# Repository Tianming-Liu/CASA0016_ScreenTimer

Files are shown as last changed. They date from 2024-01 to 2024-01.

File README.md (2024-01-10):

# *ScreenTimer*
## **CASA0016 Course Work** 
### _A Device for Screen Usage Detection and Data Visualization_

In this project, I designed a **physical device** to **detect and record** the usage time of various screens in daily life, such as the mobile phone and laptop. The primary goal is to **visually display** this data on an **interesting flip clock**.

<div align=center>
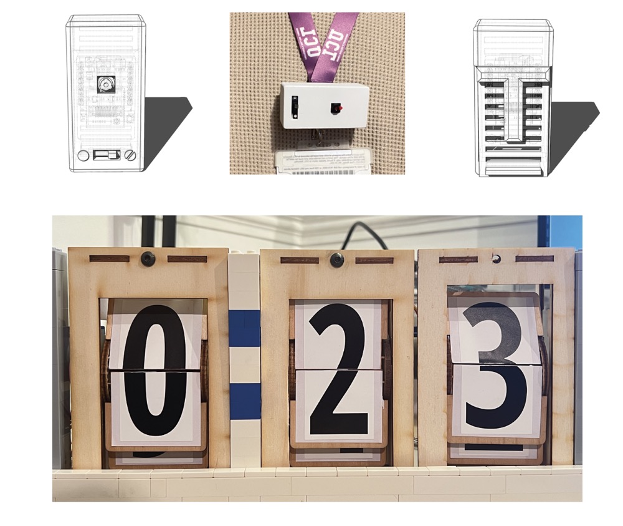
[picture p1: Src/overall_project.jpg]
Overall Photo of Website and Plant Monitor
  
</div>

## Folder Structure

```none
Screen Timer Project
├── Code (All the code for Arduino UNO, ESP32 and Rasberry Pi)
│   ├── Arduino (Code tested on Arduino UNO R4 Wifi)
│   │   ├── Final_Mqtt_MultiMotor (Integrated Code)
│   │   │   ├── Final_Mqtt_MultiMotor.ino (Main Part)
│   │   │   ├── wifiConfig.h (Create your own config file!!)
│   │   ├── Hall_Effect_Sensor_Test
│   │   │   ├── Hall_Effect_Sensor_Test.ino
│   │   ├── IO_Extender_Motor
│   │   │   ├── IO_Extender_Motor.ino
│   │   ├── LDR_Test
│   │   │   ├── LDR_Test.ino
│   │   ├── WiFiS3_test
│   │   │   ├── WiFiS3_test.ino
│   ├── ESP32 (Code tested on ESP32 With CAM Module)
│   │   ├── app_httpd.cpp
│   │   ├── camera_index.h
│   │   ├── camera_pins.h
│   │   ├── CameraWebServer.ino
│   │   ├── wifiConfig.h
│   ├── Rasp_Pi (Code tested on Rasp Pi 4B)
│   │   ├── mqttConfig.py (Create your own config file!!)
│   │   ├── test.py (Main Part)
│   │   ├── yolov8n.pt (Pretrained Model ckpt file)
├── Enclosure
│   ├── video_collection_component_enclosure.3dm (File for 3d printing)
│   ├── Enclosure/laserCut.dxf (File for Laser Cutting)
├── Src (Image and gif for README)
│   ├── ...
├── .gitignore
├── README.md (Intro)

```

## Parts List
The device consists of three components: the Video collection component, the data processing component, and the time display component.
### 1. Video Collection Component
**1.1 FREENOVE ESP32-WROVER CAM Board**

_To minimize the size of our visual data collection device while ensuring essential functionality._

<table>
  <tr>
    <td>
      <p><b>Microprocessor Selection:</b></p>
      <ul>
        <li><i>ESP32 Series</i>: Renowned for its efficiency, the ESP32 series microprocessor has been chosen for its ability to strike an optimal balance between a small form factor and robust performance.</li>
      </ul>
      <p><b>Key Benefits:</b></p>
      <ul>
        <li><i>Seamless Image Capture</i>: Compact camera module ensures high-quality data acquisition.</li>
        <li><i>Effortless Connectivity</i>: Wireless network connection module facilitates easy and reliable data transmission.</li>
      </ul>
    </td>
    <td>
      <div align="center">
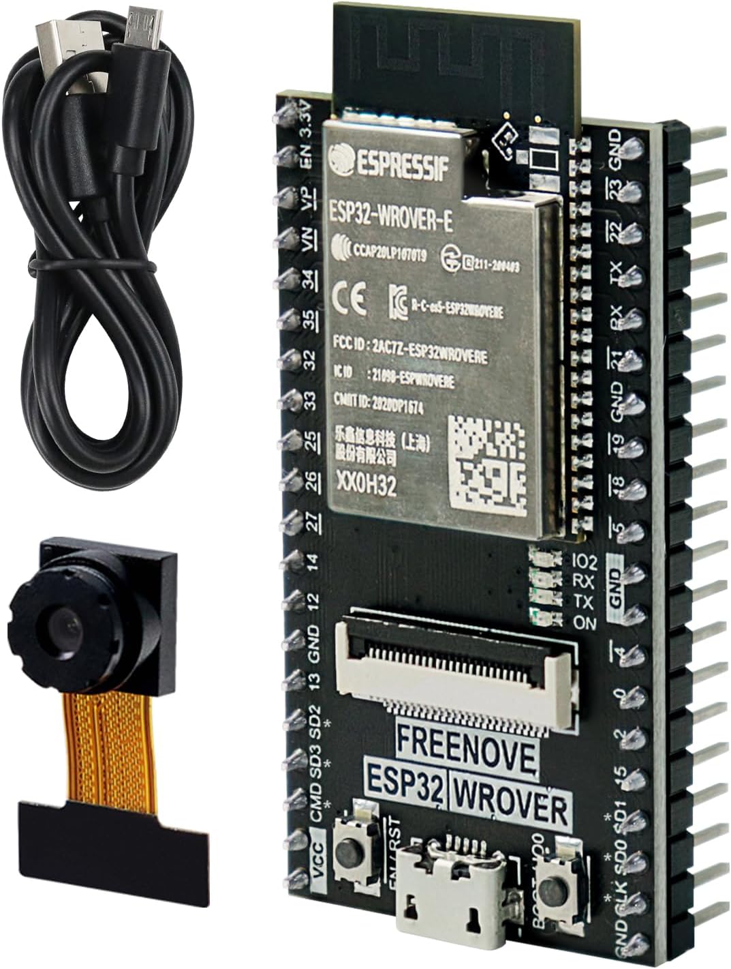
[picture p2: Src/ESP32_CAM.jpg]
        
      </div>
    </td>
  </tr>
</table>

**1.2 Lithium Polymer Battery**

_In choosing components for our project, i want to ensure that my device remains portable while delivering robust performance._

<table>
  <tr>
    <td>
      <p><b>Power Supply Selection:</b></p>
      <ul>
        <li><i>Lithium Polymer batteries</i>: are known for their high energy density and flexible form factor. Unlike traditional rigid batteries, they can be made in various shapes and sizes, which allows for more versatile design options. Their chemistry offers a good balance between weight and energy output, making them popular in portable electronics.</li>
      </ul>
      <p><b>Key Benefits:</b></p>
      <ul>
        <li><i>High Compatibility</i>: With a 3.7V nominal voltage, the Lithium Polymer battery aligns well with the ESP32's 3.3V operation.</li>
        <li><i>Compact and Lightweight</i>: Dimensions of 34.5 x 56 x 10.6 mm and a weight of 40g make this battery an excellent choice for maintaining portability.</li>
        <li><i>Efficient Energy Storage</i>: A capacity of 2000 mAh provides a reliable and long-lasting power source, suitable for extended device operation.</li>
      </ul>
    </td>
    <td>
      <div align="center">
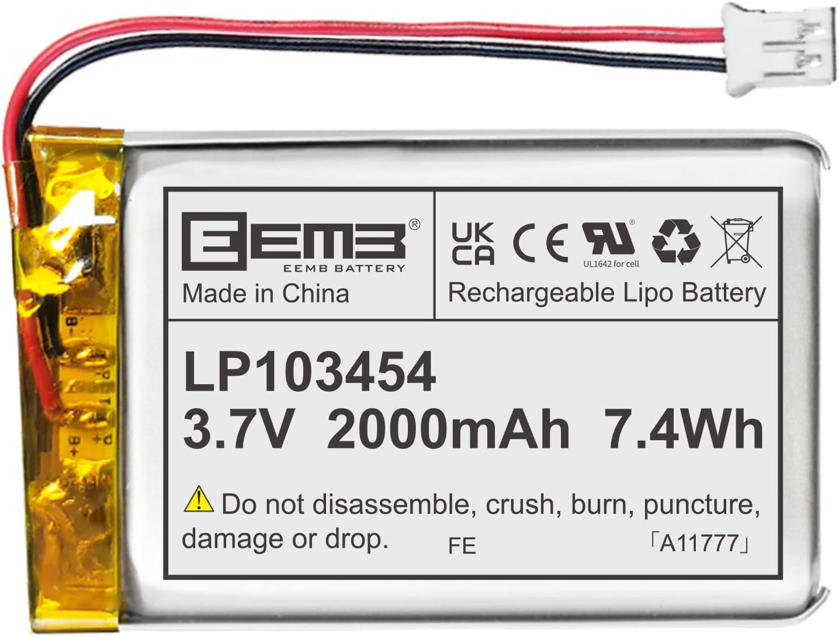
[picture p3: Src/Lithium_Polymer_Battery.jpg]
        
      </div>
    </td>
  </tr>
</table>

**1.3 Slide Switches With 3 Pin 2 Position**

_The module includes a 3-Pin 2-Position switch as the primary control for activating the screen detection device._

<table>
  <tr>
    <td>
      <p><b>Switch Type:</b></p>
      <ul>
        <li><i>Slide Switches With 3 Pin 2 Position</i> are known for its reliability and versatility, offering a clear on/off state without ambiguity. Its 3-pin configuration allows for straightforward integration into the circuit, simplifying the design and assembly process.</li>
      </ul>
      <p><b>Activation Process:</b></p>
      <ul>
        <li>When switched on, the device powers up and initiates the video data collection from the integrated camera.</li>
        <li>The captured video data is then transmitted to the data processing module for analysis.</li>
      </ul>
    </td>
    <td>
      <div align="center">
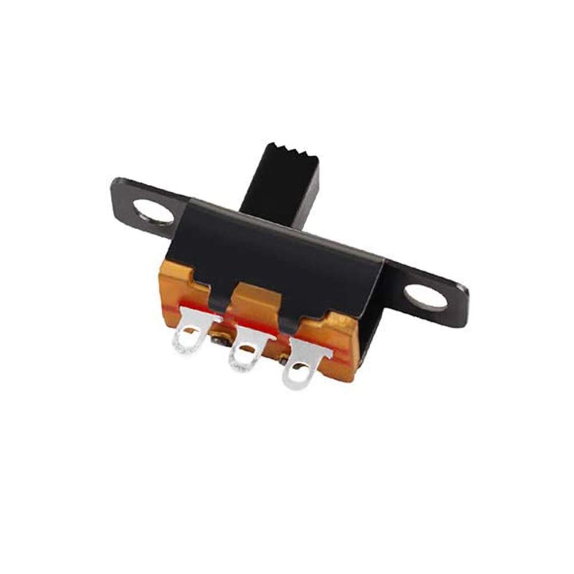
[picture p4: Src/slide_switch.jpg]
        
      </div>
    </td>
  </tr>
</table>

**1.4 3D Enclosure**

_I designed the enclosure for this component and print it out which can be attached to your clothes._

The enclosure I designed is installed in a pin-like manner, allowing for easy placement of the battery and ESP32 inside the box. There are two small holes on the front of the box; the middle opening is for the camera, and the lower opening is for toggling the switch. Symbols are placed on both sides to indicate the current status of the device. The back of the box features a clip-like design, making it convenient to attach the entire data collection box to clothing or a lanyard.

<table align=""center>
  <tr>
    <td>
        <div align="center">
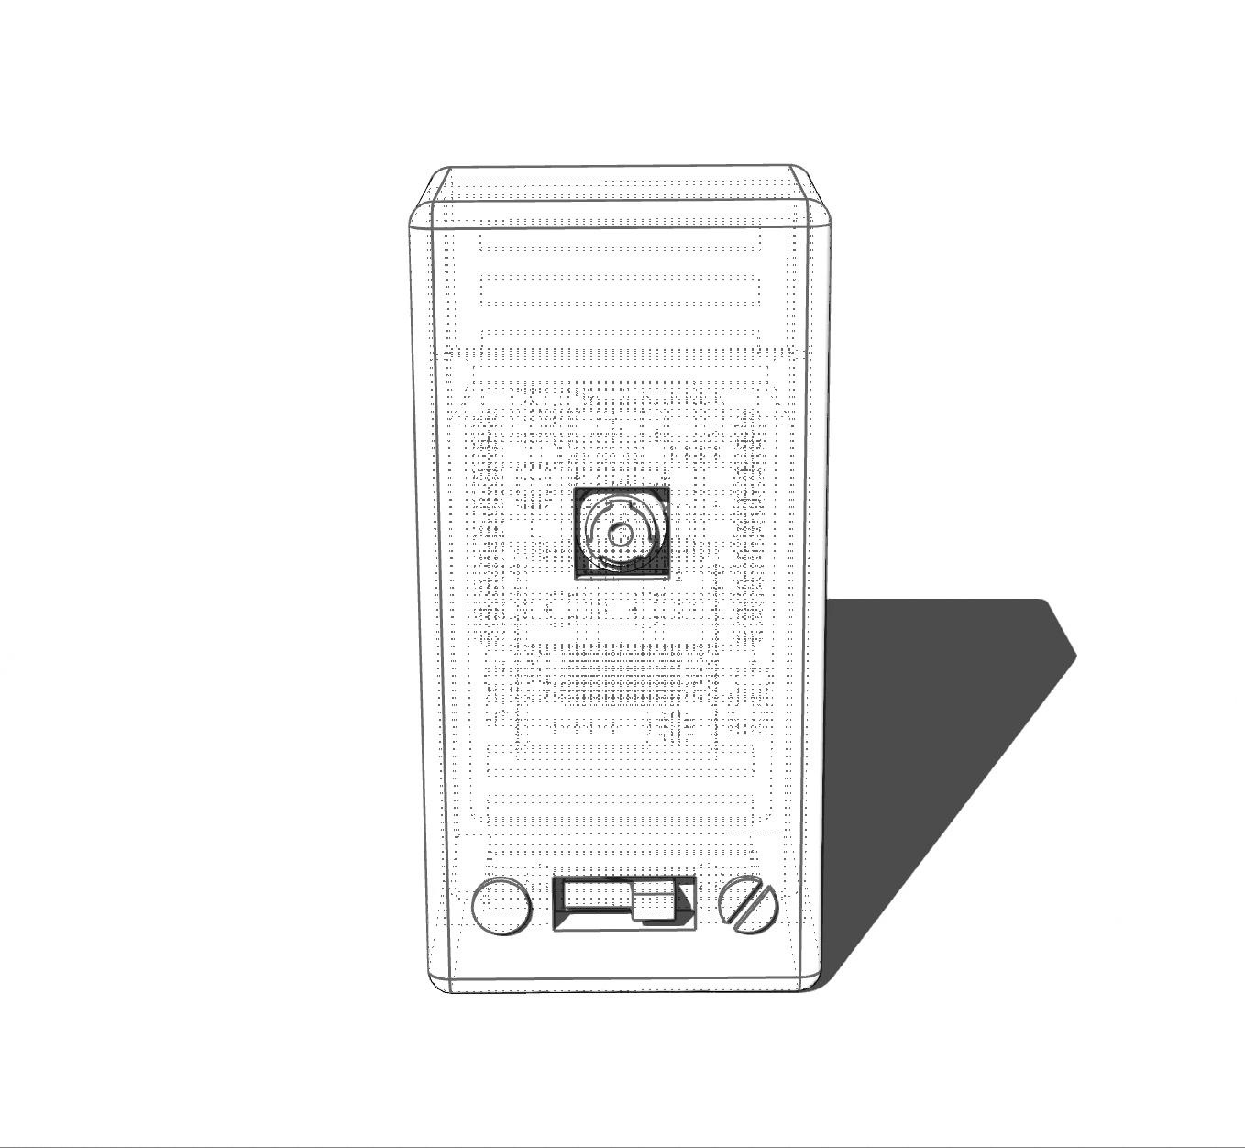
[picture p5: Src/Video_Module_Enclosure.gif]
            
        </div>
    </td>
    <td>
      <div align="center">
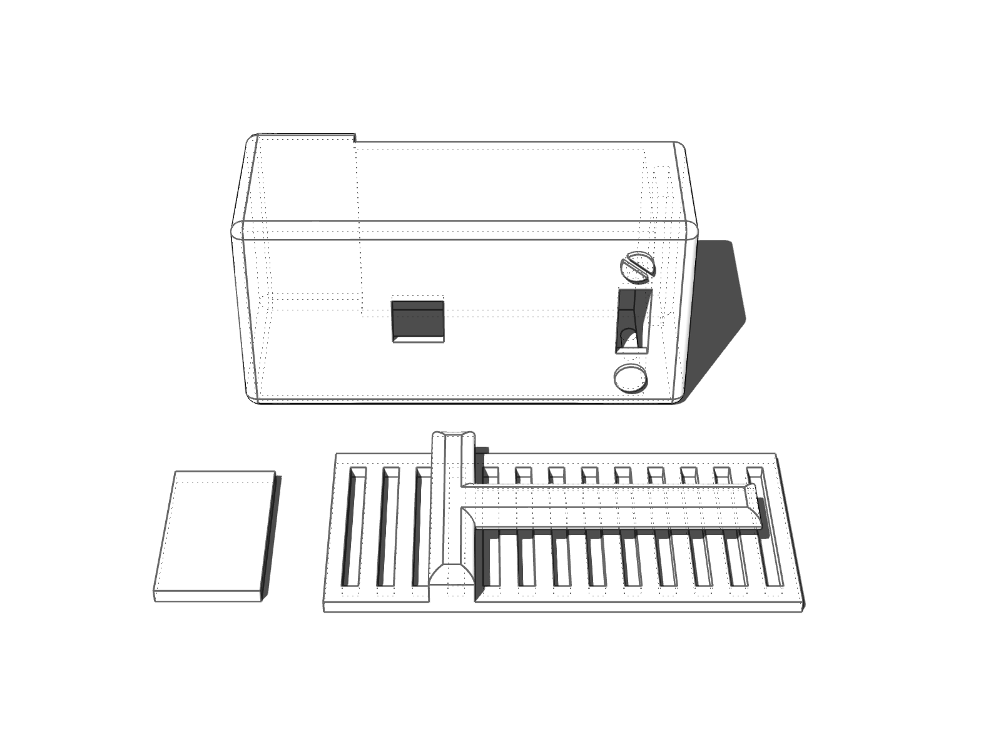
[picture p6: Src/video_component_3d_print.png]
        
      </div>
    </td>
  </tr>
</table>

You can download the 3d model in this [link](https://github.com/Tianming-Liu/CASA0016_ScreenTimer/blob/main/Enclosure/video_collection_component_enclosure.3dm).

### 2. Data Processing Component

_The Raspberry Pi 4B is mainly selected for its robust computational capabilities, essential for running lightweight deep learning models._

<table>
  <tr>
    <td>
      <p><b>Key Advantages: </b></p>
      <ul>
        <li>Efficient Deep Learning Processing: Its powerful processor and sufficient RAM enable efficient execution of deep learning algorithms, crucial for real-time data processing;</li>
        <li>Reliable Data Transmission: Offers reliable and fast data transmission capabilities, ensuring seamless integration with other components of the system; </li>
        <li>Versatile and Scalable: The Raspberry Pi 4B’s versatility makes it suitable for various applications, and its scalability allows for future enhancements and upgrades.</li>
      </ul>
    </td>
    <td>
      <div align="center">
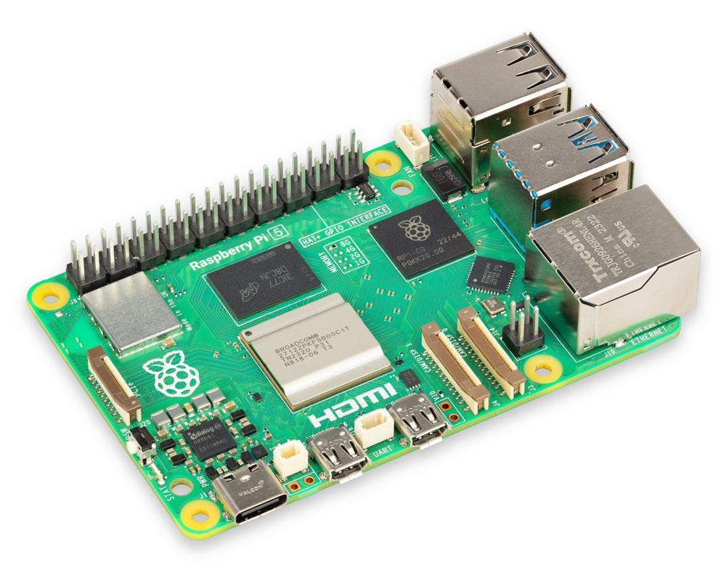
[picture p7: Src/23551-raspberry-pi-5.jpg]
        
      </div>
    </td>
  </tr>
</table>

### 3. Data Visualization Component

In this module, I control the component through the Arduino UNO R4 Wifi microprocessor. The important parts include the LDR sensor, LCD display, and a flip clock made by referencing an open-source project(Bezanson, 2019). Among these, the flip clock serves as the main activator, and I aim to express the behavior of using digital products in a de-electrified manner. The component responds to both of the screen usage time and lighting environment of the user.

<div align="center">

| Part | Image | Part | Image |
|---|---|---|---|
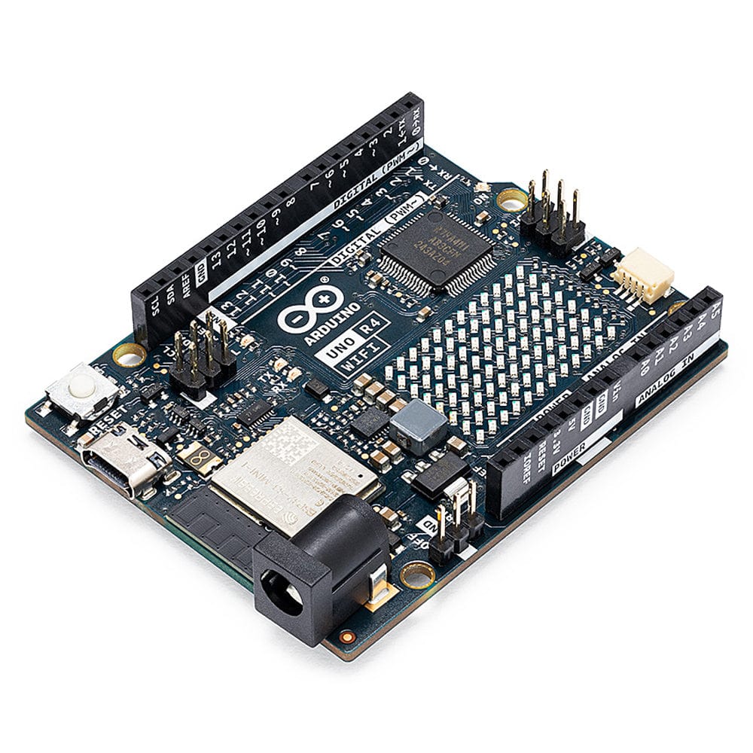
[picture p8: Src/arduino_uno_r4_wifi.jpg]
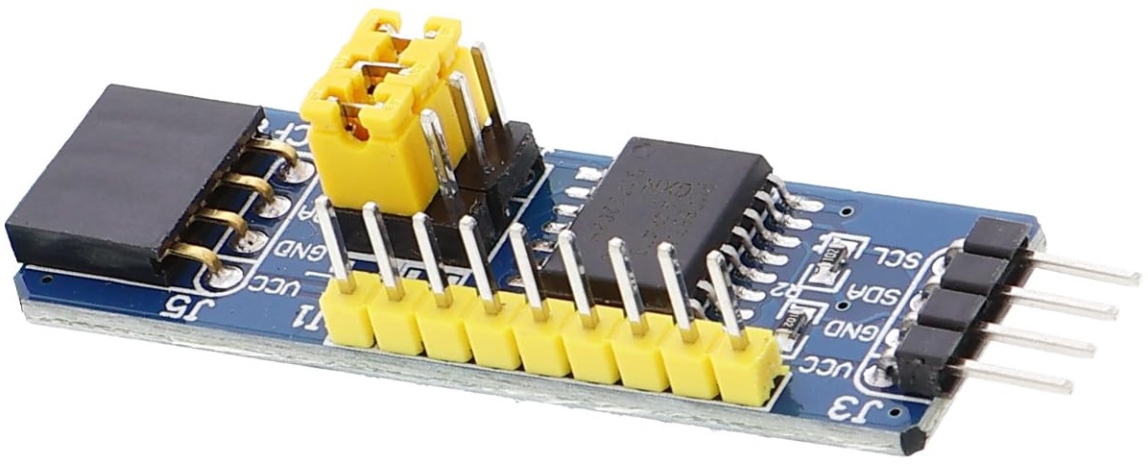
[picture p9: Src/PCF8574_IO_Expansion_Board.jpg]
| Arduino UNO R4 Wifi |  | PCF8574 IO Expansion Board |  |
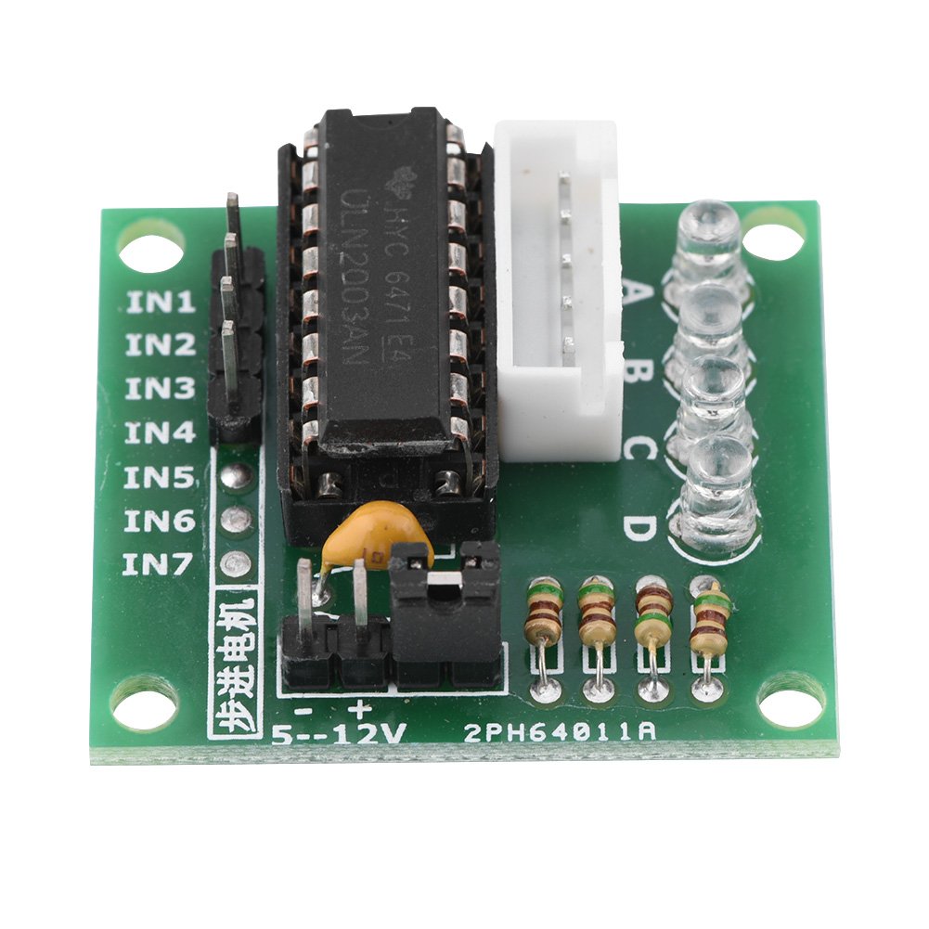
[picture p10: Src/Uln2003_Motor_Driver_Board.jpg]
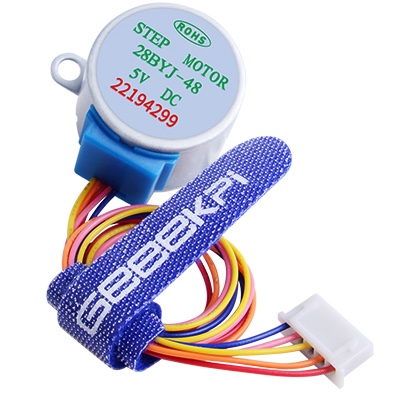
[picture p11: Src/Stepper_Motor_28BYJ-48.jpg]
| Uln2003 Motor Driver Board |  | Stepper Motor 28BYJ-48 |  |
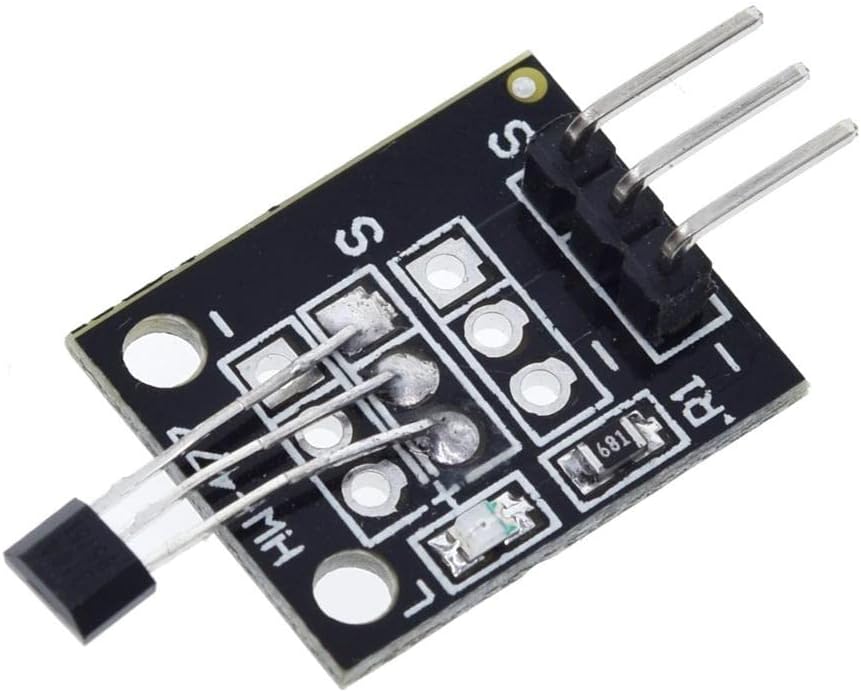
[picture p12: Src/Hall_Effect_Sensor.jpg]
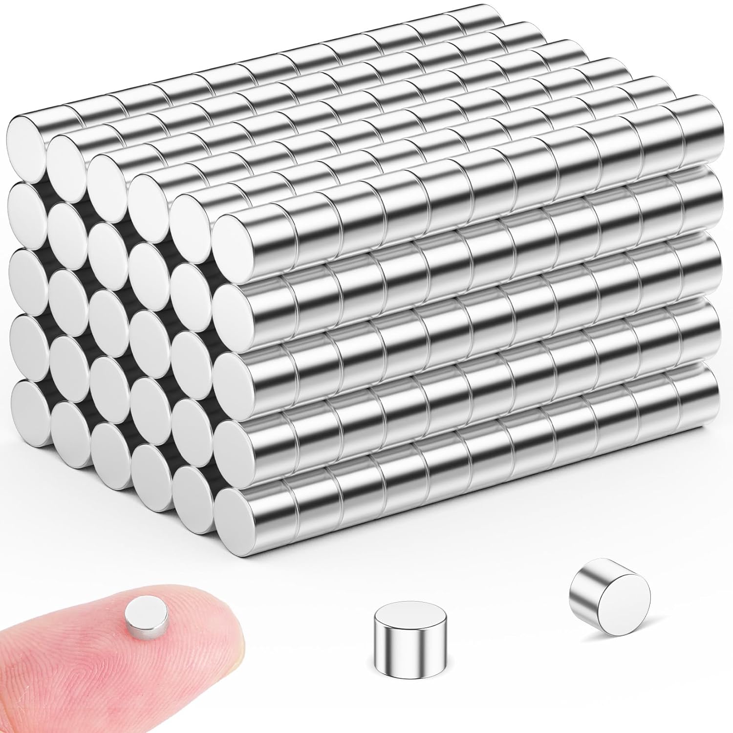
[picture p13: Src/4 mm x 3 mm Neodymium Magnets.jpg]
| Hall Effect Sensor |  | Neodymium Magnets|  |
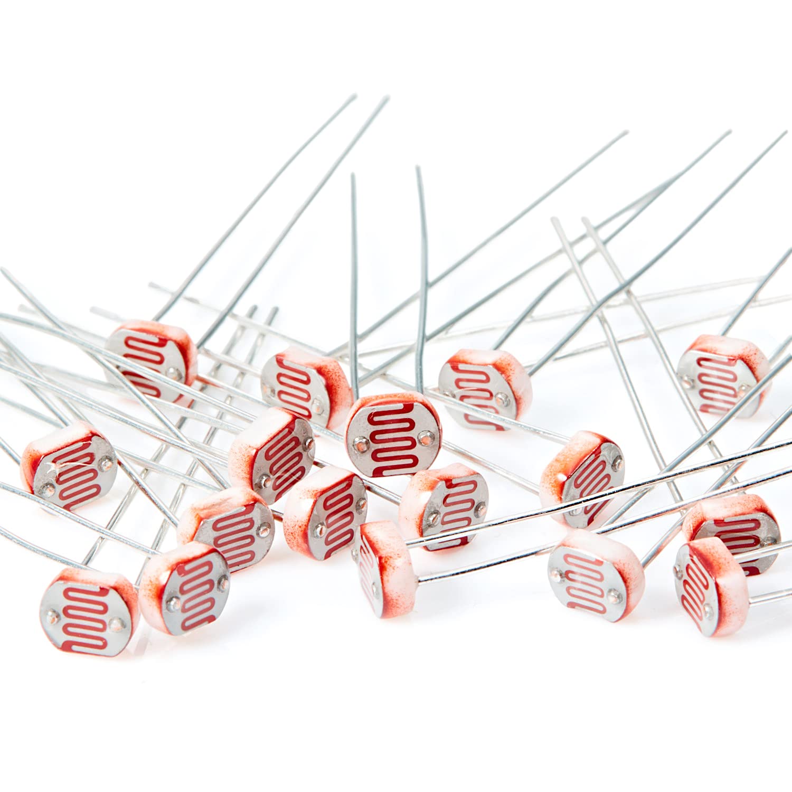
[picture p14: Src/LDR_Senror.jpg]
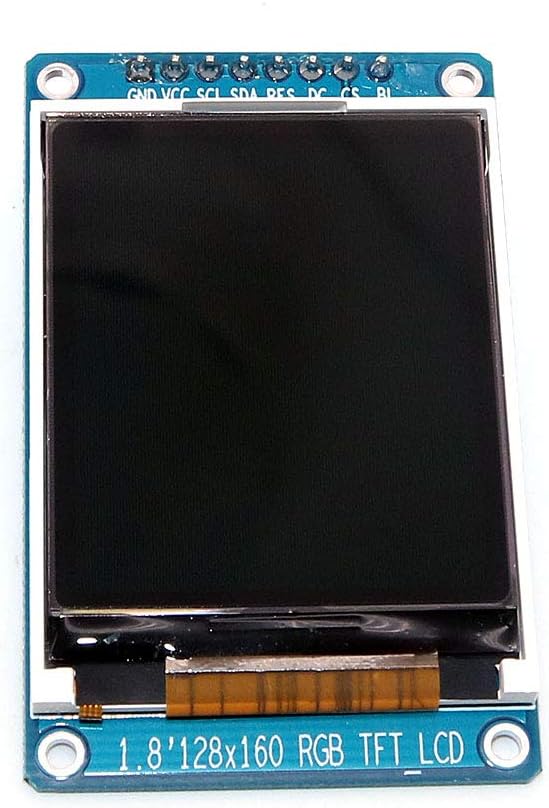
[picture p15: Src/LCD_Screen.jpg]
| LDR Sensor |  | LCD Screen |  |
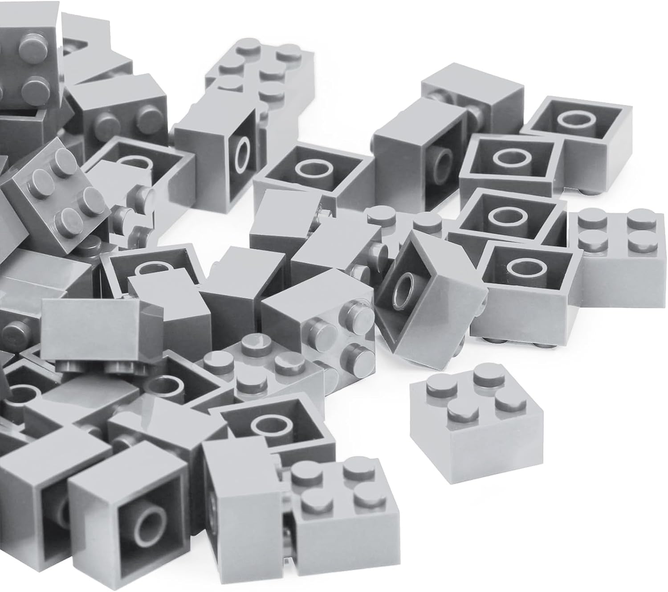
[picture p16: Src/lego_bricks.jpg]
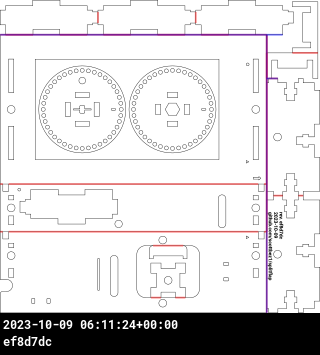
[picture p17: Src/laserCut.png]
| Lego Bricks |  | [LaserCut Enclosure](https://github.com/Tianming-Liu/CASA0016_ScreenTimer/blob/main/Enclosure/laserCut.dxf) |  |

</div>

## Results

Finally, the project achieved the process of collecting video streams using wearable cameras, processing video data on a Raspberry Pi and outputting screen usage time data, followed by displaying various screen usage times through a flip clock. Additionally, in focusing on screen usage behavior, the project also considered the quality assessment of the screen usage environment.

<div align="center">
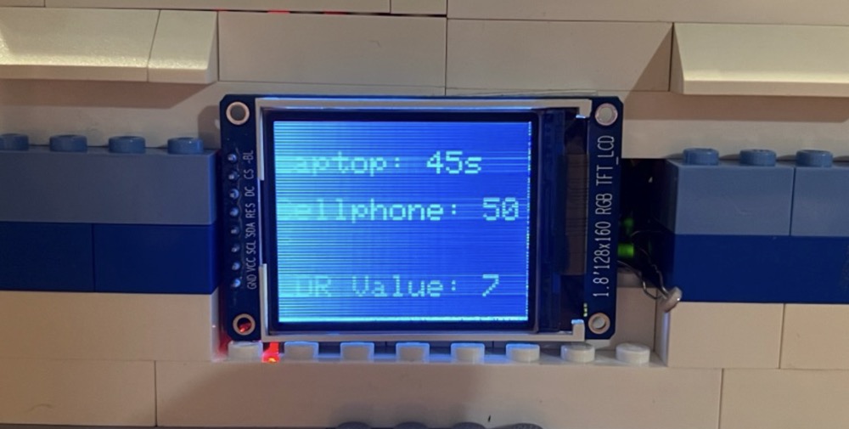
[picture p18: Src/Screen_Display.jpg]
  
</div>

<div align="center">
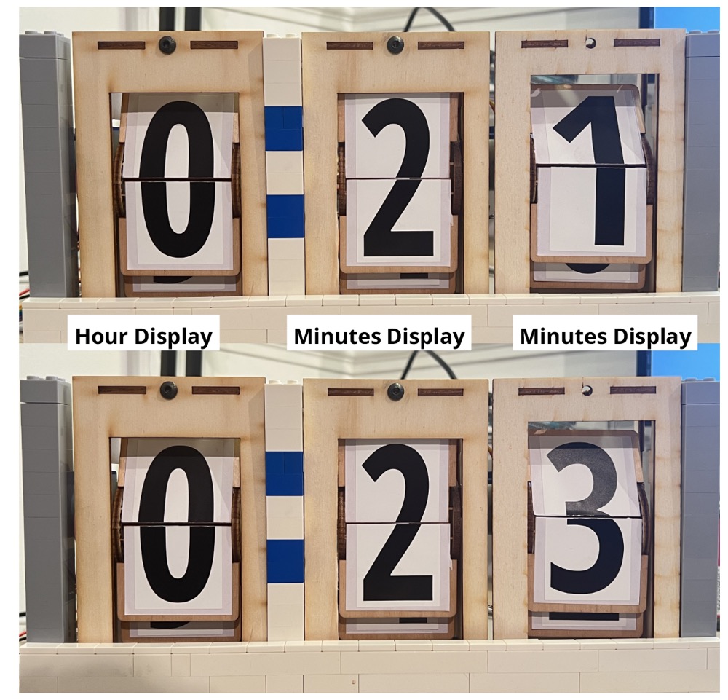
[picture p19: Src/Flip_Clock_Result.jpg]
  
</div>

The following gif shows the process of motor resetting after turnning on the device. The motor will rotate the clock panels to "0" respectively and then start to connect the MQTT so as to display the real time screen usage duration.

<div align=center>
  Overall Photo of Website and Plant Monitor
</div>

## Future

- _Enhancing Processing Efficiency and Accuracy_
Adopt models suitable for low-power devices, like TinyML, to improve the speed and accuracy of data processing on small devices like the Raspberry Pi.

- _System Optimization and Integration_
Simplify system configuration by using more powerful computing devices, and enhance device integration and ease of deployment through 3D Enclosure design.
- _Data Transmission and Expansion of Application Scenarios_
Optimize data transmission processes to expand application scenarios, making the device an efficient urban sensing tool for researchers and general users.
## Acknowledgements

This project makes use of open-source components. We acknowledge and are grateful to these developers for their contributions.

- **Splitflap Display by Scott Bezek**: This project utilizes components from the Splitflap display designed by Scott Bezek. The original project can be found at [Splitflap](https://github.com/scottbez1/splitflap#design-overview). 
- **Ultralytics YOLO**: Our project incorporates models from Ultralytics YOLO, an efficient and versatile object detection system. More information can be found at their GitHub repository [Ultralytics](https://github.com/ultralytics/ultralytics).

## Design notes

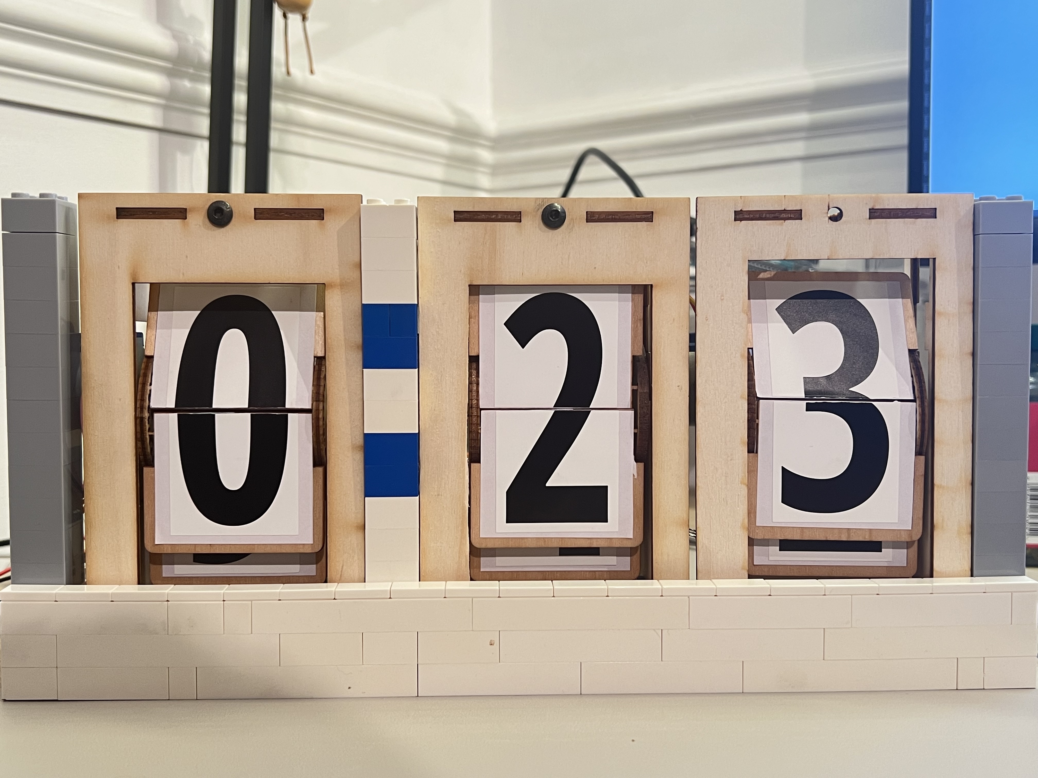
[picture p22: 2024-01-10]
Src/top01.jpg

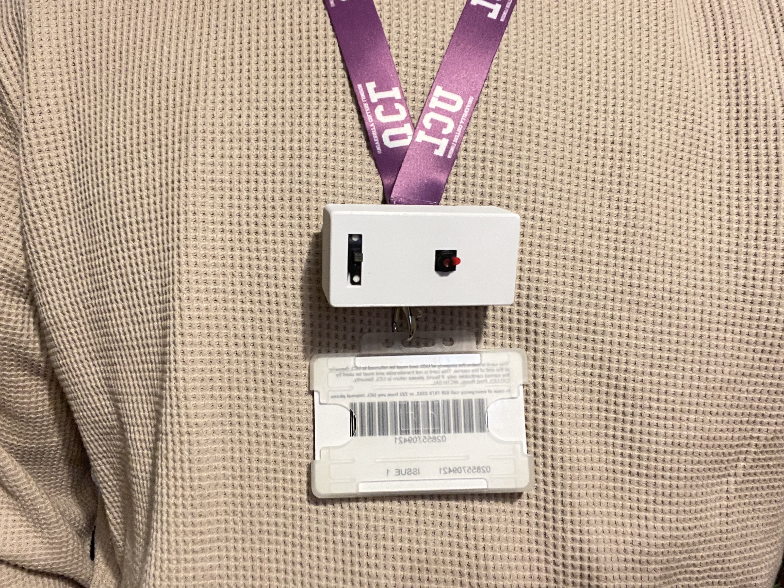
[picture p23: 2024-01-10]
Src/collection_enclosure.jpg

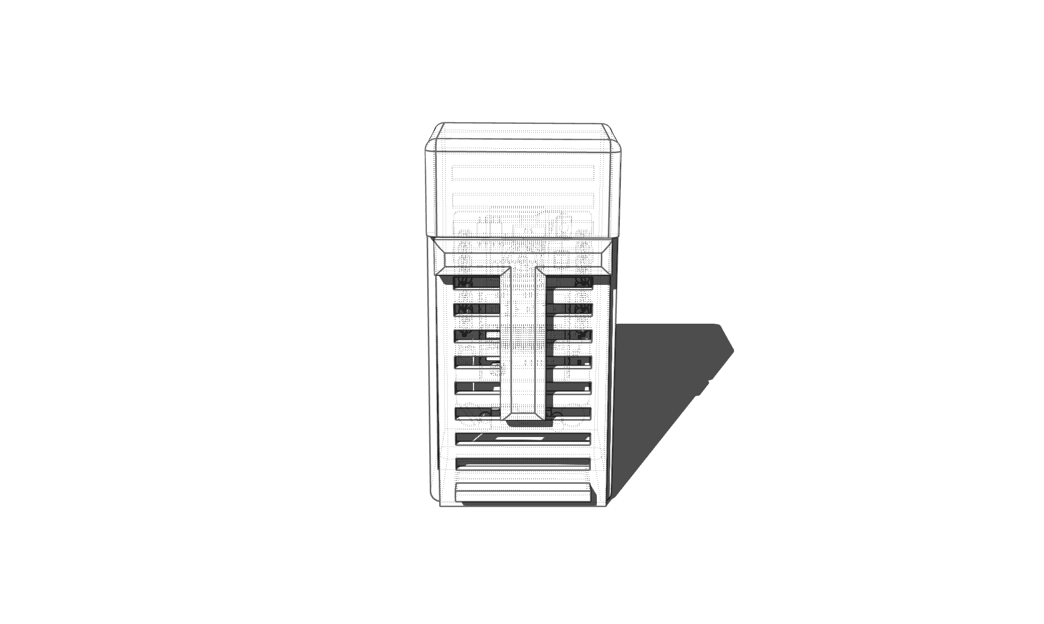
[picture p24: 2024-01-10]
Src/Back_Facade.png

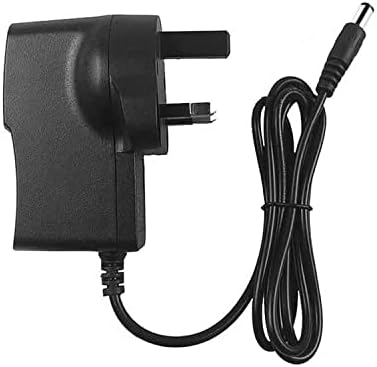
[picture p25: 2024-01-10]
Src/Power Supply Adapter.jpg

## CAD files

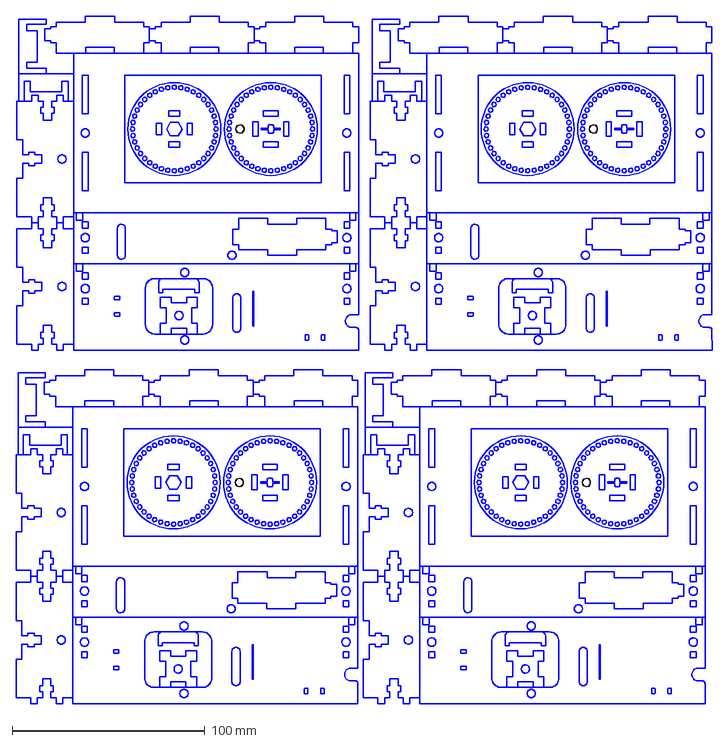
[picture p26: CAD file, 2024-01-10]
Enclosure/laserCut.dxf
361.3 x 356.9 mm

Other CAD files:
Enclosure/video_collection_component_enclosure.3dm

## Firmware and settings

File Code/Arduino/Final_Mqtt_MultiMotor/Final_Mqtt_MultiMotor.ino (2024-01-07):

#include <WiFiS3.h>
#include <PubSubClient.h>
#include <Wire.h>
#include <wifiConfig.h> // You need to create this file and define your own SSID and password

#define uint8_t unsigned char
#define PCF8574_ADD (0x40 >> 1)
#define IN1 8
#define IN2 9
#define IN3 10
#define IN4 11

// Setting up the WiFi and MQTT
const char* mqtt_server = "mqtt.cetools.org";
const int mqtt_port = 1883;

// Setting up the Stepper Motor
const int stepsPerRevolution = 4096; // Step count of the motor
const int stepsPerDigit = stepsPerRevolution / 10; // Step count of each digit
int Steps = 0;
int lastInputNumbers[3] = {0, 0, 0}; // Store the last input number of each motor
bool Direction = true; // true: clockwise, false: counterclockwise

char receivedValue[50];  // Store the received message
int durationSeconds = -1;     // Store the duration in seconds

WiFiClient wifiClient;
PubSubClient client(wifiClient);

// 电机结构体
struct Motor {
    bool useExtender;        // Use IO Extender or not
    uint8_t extenderAddress; // I/O Extender Address
    uint8_t pins[4];         // Arduino Pin Number or I/O Extender Pin Number
    int hallPin;             // Hall Effect Sensor Pin Number
};

Motor motors[] = {
    {false, 0, {8, 9, 10, 11}, 13},
    {true, PCF8574_ADD, {0, 1, 2, 3}, 12},
    {true, PCF8574_ADD, {4, 5, 6, 7}, 6}
};

void setup() {
    Serial.begin(9600);
    pinMode(IN1, OUTPUT);
    pinMode(IN2, OUTPUT);
    pinMode(IN3, OUTPUT);
    pinMode(IN4, OUTPUT);
    pinMode(motors[0].hallPin, INPUT);
    pinMode(motors[1].hallPin, INPUT);
    pinMode(motors[2].hallPin, INPUT);

    resetPosition(motors[0]); // Reset the Angle of the Motor
    resetPosition(motors[1]); 
    resetPosition(motors[2]); 

    WiFi.begin(ssid, password);
    while (WiFi.status() != WL_CONNECTED) {
        delay(500);
        Serial.print(".");
    }
    client.setServer(mqtt_server, mqtt_port);
    client.setCallback(callback);
    reconnectMQTT();
}

void loop() {
    if (!client.connected()) {
        reconnectMQTT();
    }
    client.loop();
}

void callback(char* topic, byte* payload, unsigned int length) {
    Serial.print("Message arrived [");
    Serial.print(topic);
    Serial.print("] ");

    // Empty the receivedValue
    memset(receivedValue, 0, sizeof(receivedValue));

    // Copy the payload to receivedValue
    if(length > sizeof(receivedValue) - 1) {
        length = sizeof(receivedValue) - 1;
    }

    // Copy the payload to receivedValue
    strncpy(receivedValue, (char*)payload, length);
    receivedValue[length] = '\0';  // 确保字符串以空字符结束

    // Parse the receivedValue and get the duration in seconds
    if(sscanf(receivedValue, "Total screen usage duration: %d seconds", &durationSeconds) == 1){
        // Parse the duration in seconds to hours and minutes
        int hours = durationSeconds / 3600;
        int minutes = (durationSeconds % 3600) / 60;

        // Split the hours and minutes to digits
        rotateToNumber(2, hours % 10);             // Motor 2 controls the hour's digit
        rotateToNumber(0, minutes / 10);           // Motor 0 controls the minute's tens digit
        rotateToNumber(1, minutes % 10);           // Motor 1 controls the minute's ones digit
    } else {
        // Parse failed, set the durationSeconds to -1
        durationSeconds = -1;
    }
}

void reconnectMQTT() {
    while (!client.connected()) {
        if (client.connect("arduinoClient")) {
            client.subscribe("student/CASA0016/ucfntl0/ScreenTimer");
        } else {
            delay(2000);
        }
    }
}

void stepper(Motor motor, int xw) {
     for (int x = 0; x < xw; x++) {

        switch (Steps) {
             case 0:
                  setMotorPins(motor, LOW, LOW, LOW, HIGH);
                  break;
             case 1:
                  setMotorPins(motor, LOW, LOW, HIGH, HIGH);
                  break;
             case 2:
                  setMotorPins(motor, LOW, LOW, HIGH, LOW);
                  break;
             case 3:
                  setMotorPins(motor, LOW, HIGH, HIGH, LOW);
                  break;
             case 4:
                  setMotorPins(motor, LOW, HIGH, LOW, LOW);
                  break;
             case 5:
                  setMotorPins(motor, HIGH, HIGH, LOW, LOW);
                  break;
             case 6:
                  setMotorPins(motor, HIGH, LOW, LOW, LOW);
                  break;
             case 7:
                  setMotorPins(motor, HIGH, LOW, LOW, HIGH);
                  break;
             default:
                  setMotorPins(motor, LOW, LOW, LOW, LOW);
                  break;
                  }
        SetDirection();
      }
}

void setMotorPins(Motor motor, bool in1, bool in2, bool in3, bool in4) {
    uint8_t data = 0;
    if (motor.useExtender) {
        // Update the data to be sent
        bitWrite(data, motor.pins[0], in1);
        bitWrite(data, motor.pins[1], in2);
        bitWrite(data, motor.pins[2], in3);
        bitWrite(data, motor.pins[3], in4);

        // Send the data to IO Extender
        Wire.beginTransmission(motor.extenderAddress);
        Wire.write(data);
        Wire.endTransmission();
    } else {
        // Write the data into arduino Pin
        digitalWrite(motor.pins[0], in1);
        digitalWrite(motor.pins[1], in2);
        digitalWrite(motor.pins[2], in3);
        digitalWrite(motor.pins[3], in4);
    }
}

void SetDirection() {
    // Rotate clockwise
    if (Direction == 1) {
        Steps++;
    }
    // Loop in the step case
    if (Steps > 7) {
        Steps = 0;
    }
}

void rotateToNumber(int motorIndex, int number) {
    // Calculate the step count
    int stepsToMove = (number - lastInputNumbers[motorIndex - 1]) * stepsPerDigit;
    if (stepsToMove < 0) {
        stepsToMove += stepsPerRevolution; // Make sure the rotation direction
    }

    // Rotate the corresponding Motor
    for (int i = 0; i < stepsToMove; i++) {
        stepper(motors[motorIndex - 1], 1);
        delayMicroseconds(2000);
    }
}

void resetPosition(Motor motor) {
    delay(2000);
    Serial.println(motor.pins[0]);
    Serial.println("Resetting position...");

    while (digitalRead(motor.hallPin) == HIGH) {
        stepper(motor,1);
        delayMicroseconds(2000);
    }

    Serial.println("Sensor is LOW, position reset.");
    Steps = 0; // Reset the step
}

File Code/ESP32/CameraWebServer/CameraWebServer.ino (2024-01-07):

/**********************************************************************
  Filename    : Camera Web Server
  Description : The camera images captured by the ESP32S3 are displayed on the web page.
  Auther      : www.freenove.com
  Modification: 2022/10/31
**********************************************************************/
#include "esp_camera.h"
#include <WiFi.h>


// ===================
// Select camera model
// ===================
#define CAMERA_MODEL_WROVER_KIT // Has PSRAM
//#define CAMERA_MODEL_ESP_EYE // Has PSRAM
// #define CAMERA_MODEL_ESP32S3_EYE // Has PSRAM
//#define CAMERA_MODEL_M5STACK_PSRAM // Has PSRAM
//#define CAMERA_MODEL_M5STACK_V2_PSRAM // M5Camera version B Has PSRAM
//#define CAMERA_MODEL_M5STACK_WIDE // Has PSRAM
//#define CAMERA_MODEL_M5STACK_ESP32CAM // No PSRAM
//#define CAMERA_MODEL_M5STACK_UNITCAM // No PSRAM
//#define CAMERA_MODEL_AI_THINKER // Has PSRAM
//#define CAMERA_MODEL_TTGO_T_JOURNAL // No PSRAM
// ** Espressif Internal Boards **
//#define CAMERA_MODEL_ESP32_CAM_BOARD
//#define CAMERA_MODEL_ESP32S2_CAM_BOARD
//#define CAMERA_MODEL_ESP32S3_CAM_LCD

#include "camera_pins.h"

// ===========================
// You Need to Enter your WiFi credentials in the wifiConfig External Private File
// ===========================
#include "wifiConfig.h"

void startCameraServer();

void setup() {
  Serial.begin(115200);
  Serial.setDebugOutput(true);
  Serial.println();

  camera_config_t config;
  config.ledc_channel = LEDC_CHANNEL_0;
  config.ledc_timer = LEDC_TIMER_0;
  config.pin_d0 = Y2_GPIO_NUM;
  config.pin_d1 = Y3_GPIO_NUM;
  config.pin_d2 = Y4_GPIO_NUM;
  config.pin_d3 = Y5_GPIO_NUM;
  config.pin_d4 = Y6_GPIO_NUM;
  config.pin_d5 = Y7_GPIO_NUM;
  config.pin_d6 = Y8_GPIO_NUM;
  config.pin_d7 = Y9_GPIO_NUM;
  config.pin_xclk = XCLK_GPIO_NUM;
  config.pin_pclk = PCLK_GPIO_NUM;
  config.pin_vsync = VSYNC_GPIO_NUM;
  config.pin_href = HREF_GPIO_NUM;
  config.pin_sscb_sda = SIOD_GPIO_NUM;
  config.pin_sscb_scl = SIOC_GPIO_NUM;
  config.pin_pwdn = PWDN_GPIO_NUM;
  config.pin_reset = RESET_GPIO_NUM;
  config.xclk_freq_hz = 20000000;
  config.frame_size = FRAMESIZE_SVGA;
  config.pixel_format = PIXFORMAT_JPEG; // for streaming
  config.grab_mode = CAMERA_GRAB_WHEN_EMPTY;
  config.fb_location = CAMERA_FB_IN_PSRAM;
  config.jpeg_quality = 12;
  config.fb_count = 1;
  
  // if PSRAM IC present, init with UXGA resolution and higher JPEG quality
  // for larger pre-allocated frame buffer.
  if(psramFound()){
    config.jpeg_quality = 14;
    config.fb_count = 2;
    config.grab_mode = CAMERA_GRAB_LATEST;
  } else {
    // Limit the frame size when PSRAM is not available
    config.frame_size = FRAMESIZE_SVGA;
    config.fb_location = CAMERA_FB_IN_DRAM;
  }

  // camera init
  esp_err_t err = esp_camera_init(&config);
  if (err != ESP_OK) {
    Serial.printf("Camera init failed with error 0x%x", err);
    return;
  }

  sensor_t * s = esp_camera_sensor_get();
  // initial sensors are flipped vertically and colors are a bit saturated
  // s->set_vflip(s, 1); // flip it back
  s->set_brightness(s, 1); // up the brightness just a bit
  s->set_saturation(s, 0); // lower the saturation
  
  // WiFi.begin(ssid, password);
  // WiFi.setSleep(false);

  // while (WiFi.status() != WL_CONNECTED) {
  //   delay(500);
  //   Serial.print(".");
  // }
  // Serial.println("");
  // Serial.println("WiFi connected");

  for (int i = 0; i < numWiFiCredentials; i++) {
    Serial.printf("Connecting to WiFi %d\n", i + 1);
    WiFi.begin(ssidList[i], passwordList[i]);
    WiFi.setSleep(false);

    int attempts = 0;
    while (WiFi.status() != WL_CONNECTED && attempts < 20) {
      delay(500);
      Serial.print(".");
      attempts++;
    }

    Serial.println();

    if (WiFi.status() == WL_CONNECTED) {
      Serial.println("WiFi connected");
      break;  // If connected, break out of the loop
    } else {
      Serial.println("WiFi connection failed");
      if (i < numWiFiCredentials - 1) {
        Serial.println("Trying another WiFi credential");
      } else {
        Serial.println("All WiFi credentials failed. Please check your WiFi settings.");
        return;  // If all WiFi credentials failed, exit the program
      }
    }
  }

  startCameraServer();

  Serial.print("Camera Ready! Use 'http://");
  Serial.print(WiFi.localIP());
  Serial.println("' to connect");
}

void loop() {
  // Do nothing. Everything is done in another task by the web server
  delay(10000);
}

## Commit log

2023-12-13 Upload Code for Arduino
2023-12-13 Upload Code for ESP32
    [partitions.csv]
2024-01-07 Camere Code for ESP32
2024-01-07 Upload Code for Arduino UNO R4 Wifi
2024-01-07 Test Code for Hall Effect Sensor
2024-01-07 Code for Wifi Test using Arduino UNO R4 WiFi
2024-01-07 Code for Motors using I/O Extender
2024-01-08 Update README File
    [video_collection_component_enclosure.3dm]
